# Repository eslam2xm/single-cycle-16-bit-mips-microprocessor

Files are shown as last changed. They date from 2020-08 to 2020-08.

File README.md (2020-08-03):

# Mips-Microprocessor
A 16-bit Harvard Architecture Microprocessor ready to run on Spartan-6 FPGA mounted on a PCB board. Our designed PCB layout was manufactured in China. It consists of three main layers.

## Hardware Layer
1. The first stage of the design is implementing the Microprocessor's all circuital components on a schematic sheet starting from the power supply and voltage regulation components, the FPGA, headers specified for our targeted project, and I/O port headers, VCC and GND headers and JTAG headers, also the FPGA'S essential-combined components such as the oscillator, and the caps, reset button and status LEDs, last thing is an SPI memory to store the data
the schematic consists of 7 blocks for the FPGA each block has number of pins for specific purposes, first 4 blocks represent the 4 banks of FPGA, Power Block, GND block and the JTAG interfacing pins block, each connected through nets to the other components/headers.
2. The second stage is the PCB layout design, the PCB mainly contains of 4 layers, top and bottom layers are signal layers, second layer is GND and basically it helps with noise immunity in the microprocessor other that just connecting the ground nets together, the third layer is the power layer and it is divided into 3 sections, each one supplies a specific voltage required by the components , starting from left, 5v, 3.3v, 1.2v
the USB port entry supplies power to the whole circuit, the voltage regulators on the top layer supplies the other 2 sections of the power layer
all the main components and headers are on the top layer and the bottom layer contains the capacitors and resistors needed by the main components
the voltage regulators and the FPGA require capacitors for filtering the input power as the FPGA is so sensitive to changes in voltages and any small change may damage it, the caps are located right under the FPGA in the bottom layer to achieve minimum track lengths and better functionality
there are 2 status LEDs used in the PCB, the first one is for successively programing the FPGA, and the second LED is for successively resetting the Microprocessor

## HDL Layer

> "Architecture and Design/Architecture.png" contains the full MIPS design

Includes all the main components of the microprocessor written in VHDL and Verilog
> Instruction Memory
> Program Counter
> ALU
> Register File
> RAM
> Control Unit

and all are finally Portmapped in one file.
Each component is implemented separately and reached the expectations in the test benches as indvidual component and also as integrated in the project.

The main file for VHDL is "VHDL\Microprocessor\Microprocessor.vhd"

The main file for Verilog is "Verilog\MP.v"

## Assembly Layer

An Application layer written in assembly for the system which involves interfacing with LCD and Keypad. All the LCD and Keypad drivers are self-implemented by our instruction set.

## Building and Synthesizing

You are required to download and install Xise ISE or any simulating tool that allows you to build VHDL codes to be able to build, synthesize and implement the microprocessor.

> You might encounter an ERROR
> Xise ISE might show errors about some files that aren't in the expected directory. All you have to do is redirect each '.vhd' file to your own
> directory.

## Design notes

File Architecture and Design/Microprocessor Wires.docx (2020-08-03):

Signal’s Name | From | To | Comment
Instruction (8 downto 6) | Instruction memory | Rmux2 | SRFW2 = 0
Instruction (5 downto 3) | Instruction memory | Rmux2 | SRFW2 = 1
Rmux2_to_Rmux1 | Rmux2 | Rmux1 | SRFW1 = 0
Rmux1_to_WREG | Rmux1 | WREG signal in Register file | If SRFW1 = 1 => ‘111’ RW = 1
ALU_Result | ALU | DATA mem and Rmux3 | SRFD3 = 0
D_to_DATA_in_RF | DATA mem | Rmux3 | SRFD3 = 1
Rmux3_to_Rmux4 | Rmux3 | Rmux4 | SRFD2 = 0
Program_Counter_Inc | ADDER1 | Rmux4 , PCmux3 , ADDER2 | SRFD2 = 1 PCmux3 = 0
Rmux4_to_Rmux5 | Rmux4 | Rmux5 | SRFD1 = 0
InPort_to_DATA_in_RF | InPort | Rmux5 | SRFD1 = 1
Rmux5_to_DATA_in_RF | Rmux5 | DATA_in signal in Register file | Check comp names and arch in this file
Instruction (5 downto 0) | Instruction memory | Sign extend
SE_Result | Sign extend | ALUmux1 , ADDER2 | SALU = 1
R2 | R2 register file out2 | ALUmux1 , DATAmem input | SALU = 0
ALU_B | ALUmux1 | ALU_B
R1 | R1 register file out 1 | ALU_A, PCmux1 , Outport | SPC1 = 1 DW = 1 , LOP = 1
Instruction (11 downto 9) | Instruction mem | RREG1 register file in 1
Instruction (8 downto 6) | Instruction mem | RREG2 register file in 2
Instruction (2 downto 0) | Instruction mem | ALUmux2 | SALU1 = 0 , SALU0 = 0
PCmux2_to_PCmux1 | PCmux2 | PCmux1 | SPC1 = 0
Program_Counter_Input | PCmux1 | PC
PCmux3_to_PCmux2 | PCmux3 | PCmux2 | SPC2 = 1
ADDER2_to_PCmux3 | ADDER2 | PCmux3 | SPC3 = 1
Program_Counter_Output | PC | ADDER1 , instruction mem | Increment pc
Instruction (15 downto 12) | Instruction mem | CU | OPCODE
ZF | ALU | Two AND gates | Branch
AND1_to_OR | First AND gate | OR gate | ZF.BRCE
AND2_to_OR | Second AND gate | OR gata | BRCNE.NOT(ZF)
SIG_SPC3 | Branch circuit output | PCmux3
Instruction (11 downto 0) | Instruction mem | PCmux2
ALU_FUNC | ALU_MUX2 | ALU FUNC

Instruction => دي السيجنال اللى طالعه من الانستراكشن ميمورى عالحجات الكتير اوى التانية دى

Program_Counter_Output(15 downto 12) & Instruction (11 downto 0) => دى السجنال اللى داخلة علي الماكس المسؤول عن الجامب اللى هو PCmux2

كل دول طبعا غير السجنالز اللى طالعة من الكنترول يونيت واللى اساميهم هى هى الاسامى اللى اسامة حاططها

الصورة اللى جاية دى هي الشكل النهائى بتاع البروسيسور وعليه اسامى الكومبوننت كلها بحيث تبقي فاهم ايه اللى انا كاتبه فوق ده

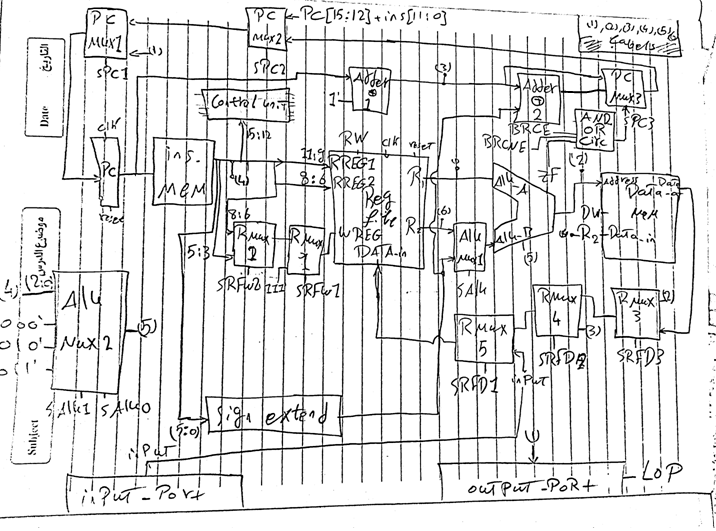
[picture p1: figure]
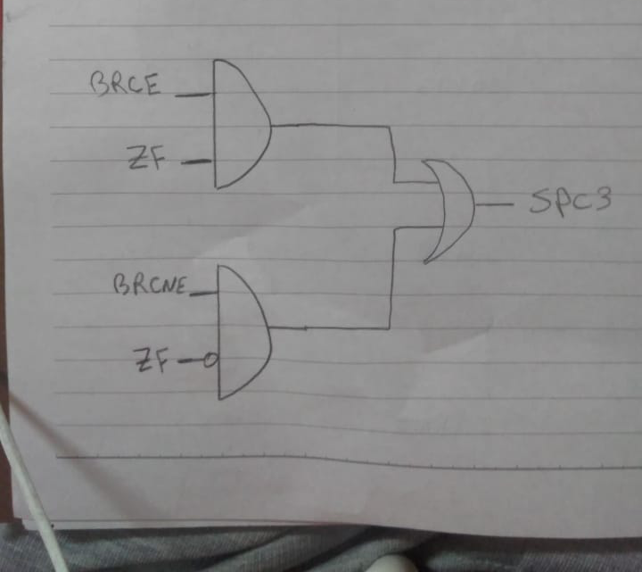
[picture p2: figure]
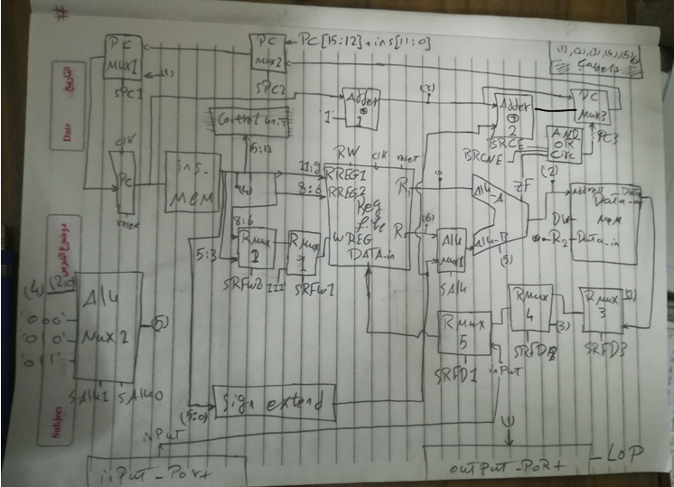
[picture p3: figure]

Instruction
,Rmux2_to_Rmux1
,Rmux1_to_WREG
,ALU_Result
,D_to_DATA_in_RF
,Rmux3_to_Rmux4
,Program_Counter_Inc
,Rmux4_to_Rmux5
,InPort_to_DATA_in_RF
,Rmux5_to_DATA_in_RF
,SE_Result
,R2
,ALU_B
,R1
,PCmux2_to_PCmux1
,Program_Counter_Input
,PCmux3_to_PCmux2
,ADDER2_to_PCmux3
,Program_Counter_Output
,ZF
,AND1_to_OR
,AND2_to_OR
,SIG_SPC3;

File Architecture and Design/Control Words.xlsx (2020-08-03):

instruction | WRF | WRAM | BRCE | BRCNE | SPC2 | SPC1 | SRFD1 | SRFD2 | SRFD3 | SRFW1 | SRFW2 | SALU | LOP | RPC | RRF | SALU1 | SALU0 | LPC
ALU8 | 1 | 0 | 0 | 0 | 1 | 0 | 0 | 0 | 0 | 0 | 1 | 0 | 0 | 0 | 0 | 0 | 0 | 0
IN | 1 | 0 | 0 | 0 | 1 | 0 | 1 | 0 | 0 | 0 | 1 | 0 | 0 | 0 | 0 | 0 | 0 | 0
OUT | 0 | 0 | 0 | 0 | 1 | 0 | 0 | 0 | 0 | 0 | 0 | 0 | 1 | 0 | 0 | 0 | 0 | 0
JR | 0 | 0 | 0 | 0 | 0 | 1 | 0 | 0 | 0 | 0 | 0 | 0 | 0 | 0 | 0 | 0 | 0 | 0
ADDI | 1 | 0 | 0 | 0 | 1 | 0 | 0 | 0 | 0 | 0 | 0 | 1 | 0 | 0 | 0 | 0 | 1 | 0
ANDI | 1 | 0 | 0 | 0 | 1 | 0 | 0 | 0 | 0 | 0 | 0 | 1 | 0 | 0 | 0 | 1 | 0 | 0
ORI | 1 | 0 | 0 | 0 | 1 | 0 | 0 | 0 | 0 | 0 | 0 | 1 | 0 | 0 | 0 | 1 | 1 | 0
LW | 1 | 0 | 0 | 0 | 1 | 0 | 0 | 0 | 1 | 0 | 0 | 1 | 0 | 0 | 0 | 0 | 1 | 0
SW | 0 | 1 | 0 | 0 | 1 | 0 | 0 | 0 | 0 | 0 | 0 | 1 | 0 | 0 | 0 | 0 | 1 | 0
BEQ | 0 | 0 | 1 | 0 | 1 | 0 | 0 | 0 | 0 | 0 | 0 | 0 | 0 | 0 | 0 | 0 | 0 | 0
BNE | 0 | 0 | 0 | 1 | 1 | 0 | 0 | 0 | 0 | 0 | 0 | 0 | 0 | 0 | 0 | 0 | 0 | 0
J | 0 | 0 | 0 | 0 | 0 | 0 | 0 | 0 | 0 | 0 | 0 | 0 | 0 | 0 | 0 | 0 | 0 | 0
JAL | 1 | 0 | 0 | 0 | 0 | 0 | 0 | 1 | 0 | 1 | 0 | 0 | 0 | 0 | 0 | 0 | 0 | 0
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

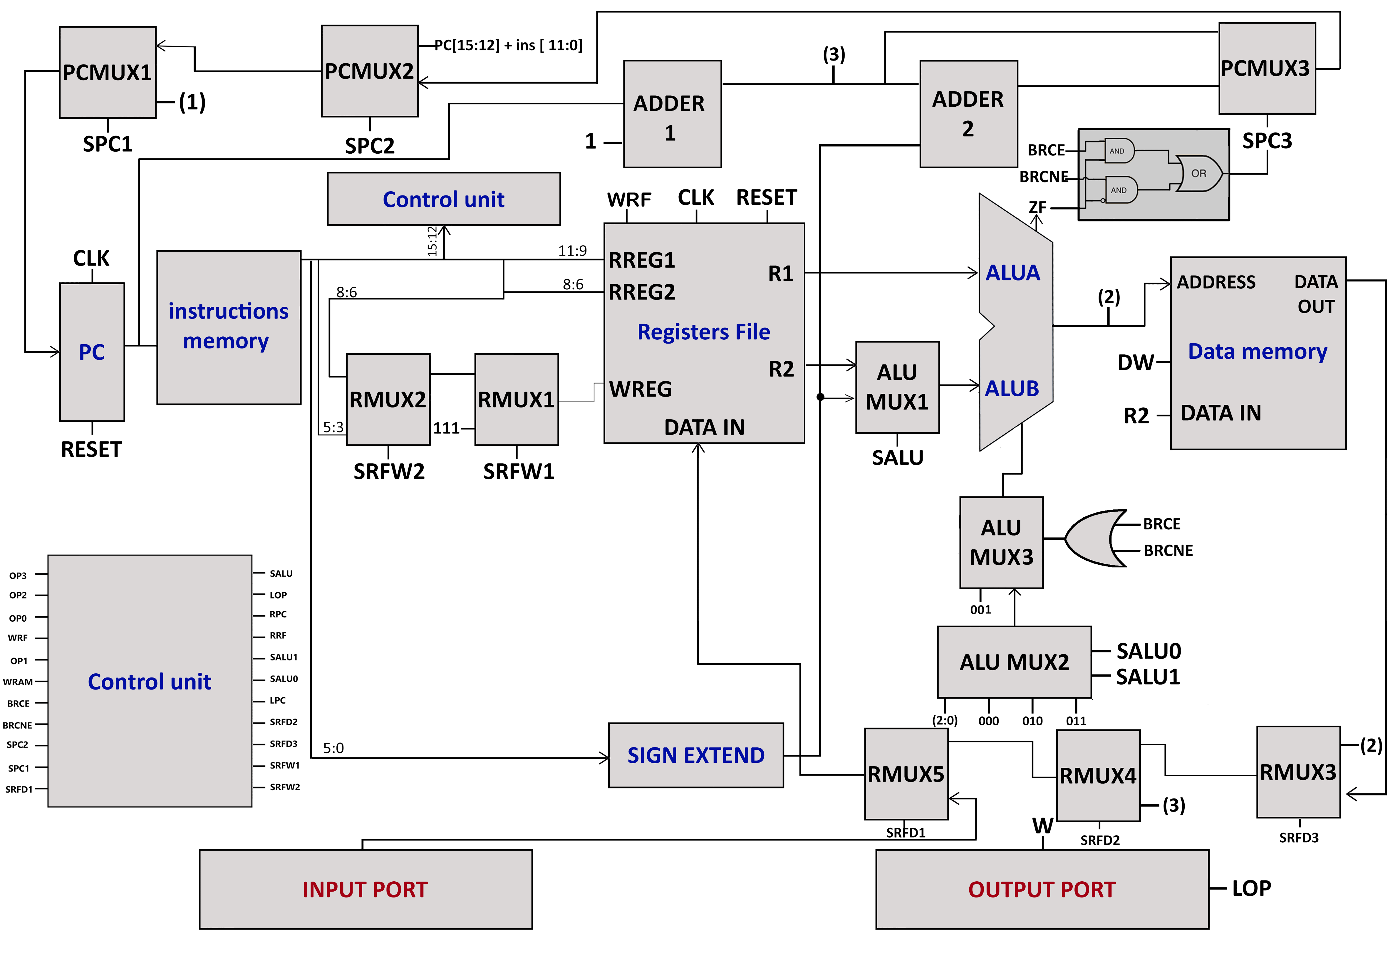
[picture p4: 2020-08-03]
Architecture and Design/Architecture .png

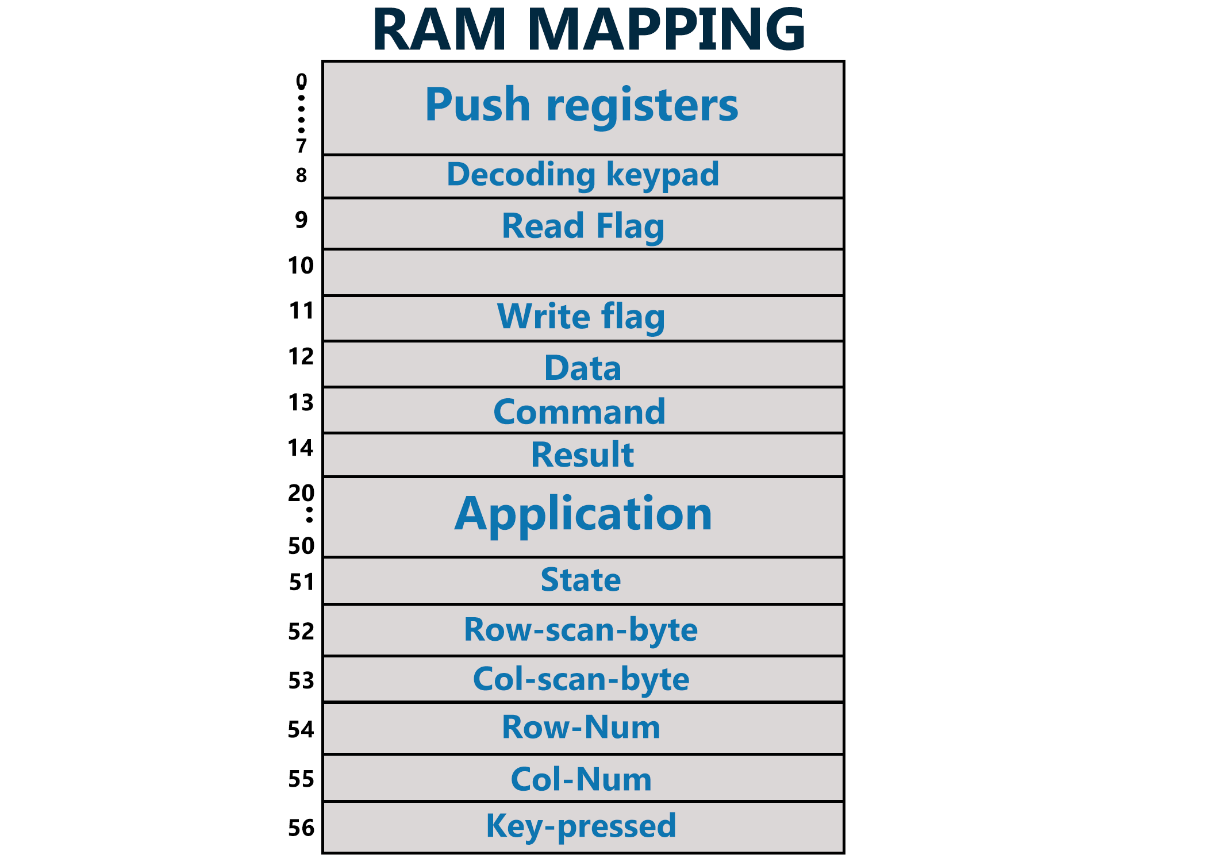
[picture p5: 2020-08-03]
Architecture and Design/RAMMAPPING.png

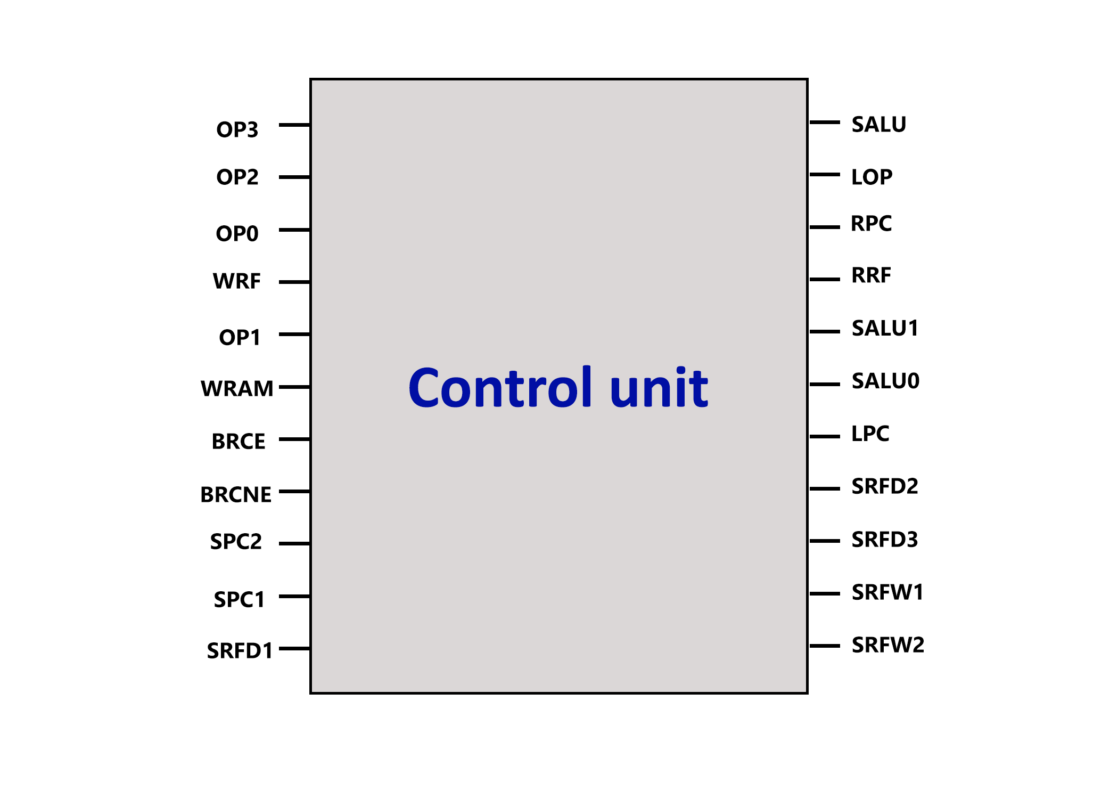
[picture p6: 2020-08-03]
Architecture and Design/Control Unit.png

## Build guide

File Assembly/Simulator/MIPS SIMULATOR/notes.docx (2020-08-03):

NOTES :

Before using the program please test each instruction beforehand so you d be sure every thing works as you intend it to be

User interface :

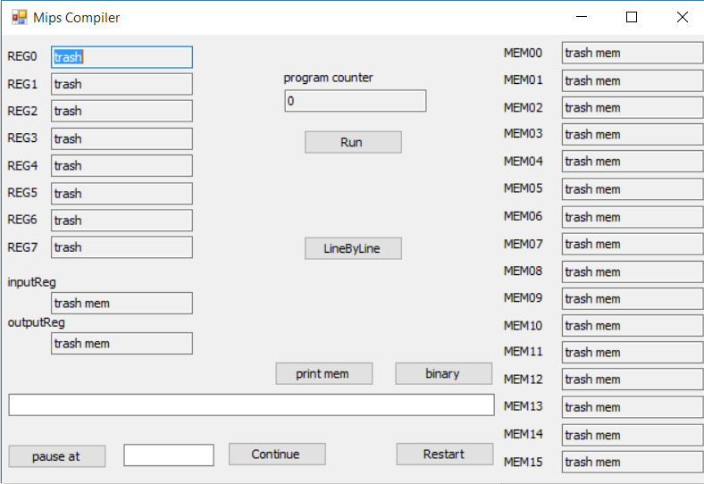
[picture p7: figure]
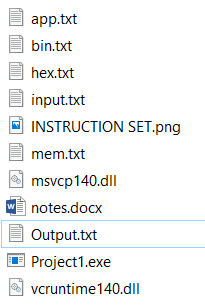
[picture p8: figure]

The program reads your application from app.txt

Press restart then run to run the entire program or line by line to ....

Binary prints your code in binary and hex , print memory prints your mem in hex values inside the file mem.txt

Pause at can pause the program when it reaches a certain line

(pause takes more time in execution so be paitent )

Continue continues the program from where u paused

All user interface values are hexdecimal

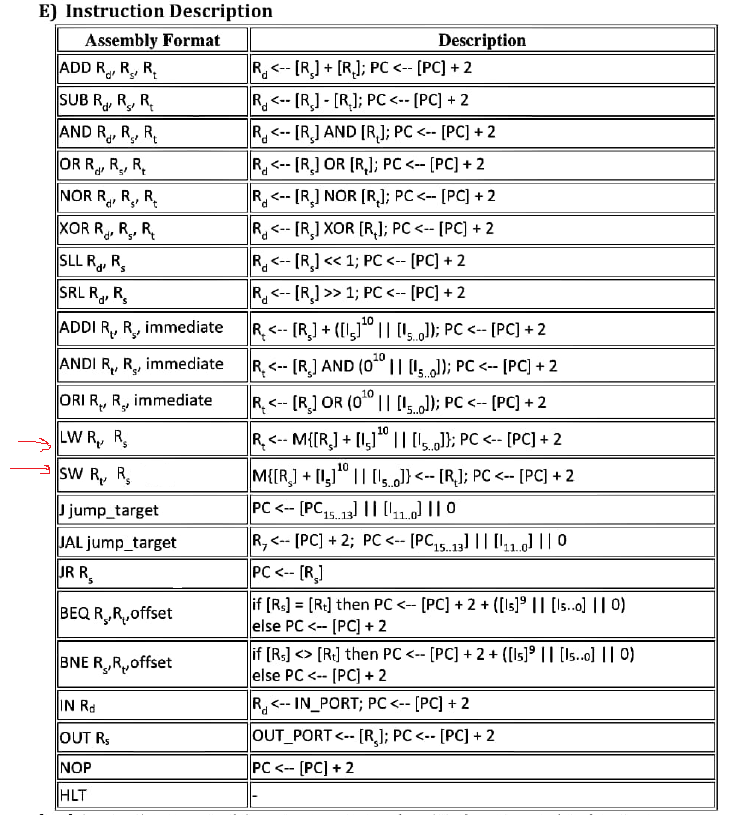
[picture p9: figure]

Please note we eraesed the offset in LW and SW

how to write instructions

*All lines have to be capital and all numbers have to be decimel

Example: ORI R6, R6, 15

*Maximum value for immidiate numbers inside the instruction is 31 ; its supposed to be 63 but it caused some problems so test it yourself before going over 31

*imidiate value for 2 is 02 not 2 and zero is 00 and so on , and ofcorse imidiate calue is decimal

*DO NOT LEAVE UNNECASRY SPACES preferably no spaces at all

Jump :

All labels has to start with a small x not X and end with “:”

Example :

J xnameOfYourLabel < no “:” when using the label

xnameOfYourLabel: ORI R6, R6, 15 → do not leave the label without instruction

لو حد عندة jump ف سطر اكبر من 2 اس 12 (حجم الجمب ف الانستراكشنز) الاسيمبلر هيترجمها لرقم غلط ف خلوا بالكم تعدلوها ب ايدكم لو عندك label ف سطر اعلى من 4096

OUT :

Puts a certain regester on the output pins so we saved every out inside the out.txt and all the numbers are in hexa

IN :

Takes input from the input pins so you will have to specify the value each time you need it inside the input.txt file

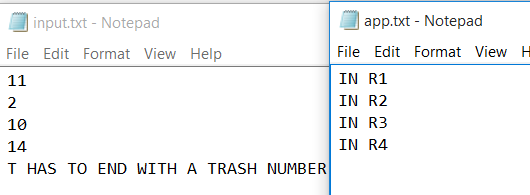
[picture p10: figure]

ALL Input are decimal values

*Memory:

As for memory file it contains only the memories that has a non zero value

Mem has 2^16 adress that is xFFFF as specified in the instruction sheet

If the program crashes that means you made an infinite loop

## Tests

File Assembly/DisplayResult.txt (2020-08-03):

// This segment get the result from Ram14 then seperates it into 5 digits and prints them to the bottom right of the LCD
//Instead of dividing by 10, we calculate the remainder first by multiplying by approx 0.9 using a series of SLL(multiplying by 2) and SRL(dividing by 2)
//----THIS SEGMENT WILL CHANGE R0~4 VALUES AND WILL NOT RETURN THEM TO THEIR INITIAL VALUES-----
//----INSTEAD R0-R4 WILL RETURN WITH ZERO VALUES----
//Used Ram14-result , Ram12-data , Ram13-command , Ram0~7- Push and Pop registers
//Used R0,R1,R2,R3,R4 in calculations and R6 to access the RAM
//Total delays of 10 LCD calls (40 ms), no local delays used

xDISPLAYRESULT: NOP
//Push R7 only, Needs to be pushed so its value can be retained to return to main after execution
SUB R6,R6,R6
ADDI R6,R6,07
SW R7,R6

//Clearing R0~6 except R5
SUB R0,R0,R0
SUB R1,R1,R1
SUB R2,R2,R2
SUB R3,R3,R3
SUB R4,R4,R4
SUB R6,R6,R6

//Get result from Ram14 in R0
ADDI R6,R6,14
LW R0,R6
//save result in R4 too
ADD R4,R4,R0
//R0 = n , R1 = q
//R0 = n>>1
SRL R0,R0
//R1 = n>>1
ADD R1,R1,R0
//R0 = n>>2
SRL R0,R0
//R1 = n>>1 + n>>2 = q
ADD R1,R1,R0
//R2 = q
SUB R2,R2,R2
ADD R2,R1,R2
//R1 = q>>4
SRL R1,R1
SRL R1,R1
SRL R1,R1
SRL R1,R1
//R2 = q + q>>4 = q
ADD R2,R2,R1
//R1 = q
SUB R1,R1,R1
ADD R1,R2,R1
//R1 = q>>8
SRL R1,R1
SRL R1,R1
SRL R1,R1
SRL R1,R1
SRL R1,R1
SRL R1,R1
SRL R1,R1
SRL R1,R1
//R2 = q + q>>8 = q
ADD R2,R2,R1
//R2 = q >> 3 = q
SRL R2,R2 
SRL R2,R2
SRL R2,R2
//R1 = q
SUB R1,R1,R1
ADD R1,R2,R1
//R2 = q<<2
SLL R2,R2
SLL R2,R2
//R2 = q<<2 + q
ADD R2,R1,R2
// R2 = (q<<2 + q) << 1
SLL R2,R2
//R0 = result
SUB R0,R0,R0
ADD R0,R0,R4
//R2 = result - ((q<<2) + q) << 1) = r
SUB R2,R0,R2
//R3 = r
SUB R3,R3,R3
ADD R3,R2,R3
//R3 = r+6
ADDI R3,R3,06
//R3 = (r+6)>>4
SRL R3,R3
SRL R3,R3
SRL R3,R3
SRL R3,R3
//R1 = q + ((r+6)>>4) = q DIVISION RESULT
ADD R1,R1,R3
//R0 = result - 10*q      DIVISION REMAINDER
SUB R0,R0,R1
SUB R0,R0,R1
SUB R0,R0,R1
SUB R0,R0,R1
SUB R0,R0,R1
SUB R0,R0,R1
SUB R0,R0,R1
SUB R0,R0,R1
SUB R0,R0,R1
SUB R0,R0,R1
//
//Now the divion result is in R1 and the remainder is in R0
//we will print the remainder in row 2 col 16 and repeat the whole code 4 more times
// row 2 col 16 is command 207 :(
//
//R2 = 207
SUB R2,R2,R2
ADDI R2,R2,31
ADDI R2,R2,31
ADDI R2,R2,31
ADDI R2,R2,31
ADDI R2,R2,31
ADDI R2,R2,31
ADDI R2,R2,21
// Store in Ram13-command
SUB R6,R6,R6
ADDI R6,R6,13
SW R2,R6
//-----------------------------------------------CALL LCD COMMAND ---------------------------------------------
JAL xSENDCMD
//Change R0 to ascii by adding 0x30 = 48
ADDI R0,R0,30
ADDI R0,R0,18
// Store in Ram12-data
SUB R6,R6,R6
ADDI R6,R6,12
SW R0,R6
//------------------------------------------------CALL LCD DATA---------------------------------------------
JAL xSENDDATA
//////////////////////////////////////////////////////////////////////////////////////////
//////////////////////////////////////////////////////////////////////////////////////////
//                          FIRST DIVISION IS DONE				 	//
//			    1 number is displayed					//
//////////////////////////////////////////////////////////////////////////////////////////
//////////////////////////////////////////////////////////////////////////////////////////
// Put the result of division in R0 and R4, from R1 and repeat the whole division 3 times but print in 206~203
SUB R4,R4,R4
ADD R4,R1,R4
SUB R0,R0,R0
ADD R0,R1,R0
SUB R1,R1,R1
SUB R2,R2,R2
SUB R3,R3,R3
//
//
//Now repeating the division -- 2nd time
//
//
//R0 = n , R1 = q
//R0 = n>>1
SRL R0,R0
//R1 = n>>1
ADD R1,R1,R0
//R0 = n>>2
SRL R0,R0
//R1 = n>>1 + n>>2 = q
ADD R1,R1,R0
//R2 = q
SUB R2,R2,R2
ADD R2,R1,R2
//R1 = q>>4
SRL R1,R1
SRL R1,R1
SRL R1,R1
SRL R1,R1
//R2 = q + q>>4 = q
ADD R2,R2,R1
//R1 = q
SUB R1,R1,R1
ADD R1,R2,R1
//R1 = q>>8
SRL R1,R1
SRL R1,R1
SRL R1,R1
SRL R1,R1
SRL R1,R1
SRL R1,R1
SRL R1,R1
SRL R1,R1
//R2 = q + q>>8 = q
ADD R2,R2,R1
//R2 = q >> 3 = q
SRL R2,R2 
SRL R2,R2
SRL R2,R2
//R1 = q
SUB R1,R1,R1
ADD R1,R2,R1
//R2 = q<<2
SLL R2,R2
SLL R2,R2
//R2 = q<<2 + q
ADD R2,R1,R2
// R2 = (q<<2 + q) << 1
SLL R2,R2
//R0 = result
SUB R0,R0,R0
ADD R0,R0,R4
//R2 = result - ((q<<2) + q) << 1) = r
SUB R2,R0,R2
//R3 = r
SUB R3,R3,R3
ADD R3,R2,R3
//R3 = r+6
ADDI R3,R3,06
//R3 = (r+6)>>4
SRL R3,R3
SRL R3,R3
SRL R3,R3
SRL R3,R3
//R1 = q + ((r+6)>>4) = q DIVISION RESULT
ADD R1,R1,R3
//R0 = result - 10*q      DIVISION REMAINDER
SUB R0,R0,R1
SUB R0,R0,R1
SUB R0,R0,R1
SUB R0,R0,R1
SUB R0,R0,R1
SUB R0,R0,R1
SUB R0,R0,R1
SUB R0,R0,R1
SUB R0,R0,R1
SUB R0,R0,R1
//
//Now the divion result is in R1 and the remainder is in R0
//we will print the remainder in row 2 col 15 and repeat the whole code 4 more times
// row 2 col 16 is command 206 
//
//R2 = 206
SUB R2,R2,R2
ADDI R2,R2,31
ADDI R2,R2,31
ADDI R2,R2,31
ADDI R2,R2,31
ADDI R2,R2,31
ADDI R2,R2,31
ADDI R2,R2,20
// Store in Ram13-command
SUB R6,R6,R6
ADDI R6,R6,13
SW R2,R6
//-----------------------------------------------CALL LCD COMMAND ---------------------------------------------
JAL xSENDCMD
//Change R0 to ascii by adding 0x30 = 48
ADDI R0,R0,30
ADDI R0,R0,18
// Store in Ram12-data
SUB R6,R6,R6
ADDI R6,R6,12
SW R0,R6
//------------------------------------------------CALL LCD DATA---------------------------------------------
JAL xSENDDATA
//////////////////////////////////////////////////////////////////////////////////////////
//////////////////////////////////////////////////////////////////////////////////////////
//                          SECOND DIVISION IS DONE				 	//
//			    2 numbers are displayed					//
//////////////////////////////////////////////////////////////////////////////////////////
//////////////////////////////////////////////////////////////////////////////////////////
//  Put the result of division in R0 and R4, from R1 and repeat the whole division 2 more times but print in 205~203
SUB R4,R4,R4
ADD R4,R1,R4
SUB R0,R0,R0
ADD R0,R1,R0
SUB R1,R1,R1
SUB R2,R2,R2
SUB R3,R3,R3
//
//
//Now repeating the division -- 3rd time
//
//
//R0 = n , R1 = q
//R0 = n>>1
SRL R0,R0
//R1 = n>>1
ADD R1,R1,R0
//R0 = n>>2
SRL R0,R0
//R1 = n>>1 + n>>2 = q
ADD R1,R1,R0
//R2 = q
SUB R2,R2,R2
ADD R2,R1,R2
//R1 = q>>4
SRL R1,R1
SRL R1,R1
SRL R1,R1
SRL R1,R1
//R2 = q + q>>4 = q
ADD R2,R2,R1
//R1 = q
SUB R1,R1,R1
ADD R1,R2,R1
//R1 = q>>8
SRL R1,R1
SRL R1,R1
SRL R1,R1
SRL R1,R1
SRL R1,R1
SRL R1,R1
SRL R1,R1
SRL R1,R1
//R2 = q + q>>8 = q
ADD R2,R2,R1
//R2 = q >> 3 = q
SRL R2,R2 
SRL R2,R2
SRL R2,R2
//R1 = q
SUB R1,R1,R1
ADD R1,R2,R1
//R2 = q<<2
SLL R2,R2
SLL R2,R2
//R2 = q<<2 + q
ADD R2,R1,R2
// R2 = (q<<2 + q) << 1
SLL R2,R2
//R0 = result
SUB R0,R0,R0
ADD R0,R0,R4
LW R0,R6
//R2 = result - ((q<<2) + q) << 1) = r
SUB R2,R0,R2
//R3 = r
SUB R3,R3,R3
ADD R3,R2,R3
//R3 = r+6
ADDI R3,R3,06
//R3 = (r+6)>>4
SRL R3,R3
SRL R3,R3
SRL R3,R3
SRL R3,R3
//R1 = q + ((r+6)>>4) = q DIVISION RESULT
ADD R1,R1,R3
//R0 = result - 10*q      DIVISION REMAINDER
SUB R0,R0,R1
SUB R0,R0,R1
SUB R0,R0,R1
SUB R0,R0,R1
SUB R0,R0,R1
SUB R0,R0,R1
SUB R0,R0,R1
SUB R0,R0,R1
SUB R0,R0,R1
SUB R0,R0,R1
//
//Now the divion result is in R1 and the remainder is in R0
//we will print the remainder in row 2 col 14 and repeat the code 2 more times
// row 2 col 16 is command 206 
//
//R2 = 205
SUB R2,R2,R2
ADDI R2,R2,31
ADDI R2,R2,31
ADDI R2,R2,31
ADDI R2,R2,31
ADDI R2,R2,31
ADDI R2,R2,31
ADDI R2,R2,19
// Store in Ram13-command
SUB R6,R6,R6
ADDI R6,R6,13
SW R2,R6
//-----------------------------------------------CALL LCD COMMAND ---------------------------------------------
JAL xSENDCMD
//Change R0 to ascii by adding 0x30 = 48
ADDI R0,R0,30
ADDI R0,R0,18
// Store in Ram12-data
SUB R6,R6,R6
ADDI R6,R6,12
SW R0,R6
//------------------------------------------------CALL LCD DATA---------------------------------------------
JAL xSENDDATA
//  Put the result of division in R0 and R4, from R1 and repeat the whole division 3 more times but print in 205~203
SUB R0,R0,R0
ADD R0,R1,R0
SUB R1,R1,R1
SUB R2,R2,R2
SUB R3,R3,R3
//////////////////////////////////////////////////////////////////////////////////////////
//////////////////////////////////////////////////////////////////////////////////////////
//                          THIRED DIVISION IS DONE				 	//
//			    3 numbers are displayed					//
//////////////////////////////////////////////////////////////////////////////////////////
//////////////////////////////////////////////////////////////////////////////////////////
//  Put the result of division in R0 and R4, from R1 and repeat the whole division 1 more time but print in 204~203
SUB R4,R4,R4
ADD R4,R1,R4
SUB R0,R0,R0
ADD R0,R1,R0
SUB R1,R1,R1
SUB R2,R2,R2
SUB R3,R3,R3
//
//
//Now repeating the division -- 4th time
//
//
//R0 = n , R1 = q
//R0 = n>>1
SRL R0,R0
//R1 = n>>1
ADD R1,R1,R0
//R0 = n>>2
SRL R0,R0
//R1 = n>>1 + n>>2 = q
ADD R1,R1,R0
//R2 = q
SUB R2,R2,R2
ADD R2,R1,R2
//R1 = q>>4
SRL R1,R1
SRL R1,R1
SRL R1,R1
SRL R1,R1
//R2 = q + q>>4 = q
ADD R2,R2,R1
//R1 = q
SUB R1,R1,R1
ADD R1,R2,R1
//R1 = q>>8
SRL R1,R1
SRL R1,R1
SRL R1,R1
SRL R1,R1
SRL R1,R1
SRL R1,R1
SRL R1,R1
SRL R1,R1
//R2 = q + q>>8 = q
ADD R2,R2,R1
//R2 = q >> 3 = q
SRL R2,R2 
SRL R2,R2
SRL R2,R2
//R1 = q
SUB R1,R1,R1
ADD R1,R2,R1
//R2 = q<<2
SLL R2,R2
SLL R2,R2
//R2 = q<<2 + q
ADD R2,R1,R2
// R2 = (q<<2 + q) << 1
SLL R2,R2
//R0 = result
SUB R0,R0,R0
ADD R0,R0,R4
LW R0,R6
//R2 = result - ((q<<2) + q) << 1) = r
SUB R2,R0,R2
//R3 = r
SUB R3,R3,R3
ADD R3,R2,R3
//R3 = r+6
ADDI R3,R3,06
//R3 = (r+6)>>4
SRL R3,R3
SRL R3,R3
SRL R3,R3
SRL R3,R3
//R1 = q + ((r+6)>>4) = q DIVISION RESULT
ADD R1,R1,R3
//R0 = result - 10*q      DIVISION REMAINDER
SUB R0,R0,R1
SUB R0,R0,R1
SUB R0,R0,R1
SUB R0,R0,R1
SUB R0,R0,R1
SUB R0,R0,R1
SUB R0,R0,R1
SUB R0,R0,R1
SUB R0,R0,R1
SUB R0,R0,R1
//
//Now the divion result is in R1 and the remainder is in R0
//we will print the remainder in row 2 col 13
// row 2 col 13 is command 204 
//
//R2 = 204
SUB R2,R2,R2
ADDI R2,R2,31
ADDI R2,R2,31
ADDI R2,R2,31
ADDI R2,R2,31
ADDI R2,R2,31
ADDI R2,R2,31
ADDI R2,R2,18
// Store in Ram13-command
SUB R6,R6,R6
ADDI R6,R6,13
SW R2,R6
//-----------------------------------------------CALL LCD COMMAND ---------------------------------------------
JAL xSENDCMD
//Change R0 to ascii by adding 0x30 = 48
ADDI R0,R0,30
ADDI R0,R0,18
// Store in Ram12-data
SUB R6,R6,R6
ADDI R6,R6,12
SW R0,R6
//------------------------------------------------CALL LCD DATA---------------------------------------------
JAL xSENDDATA
//////////////////////////////////////////////////////////////////////////////////////////
//////////////////////////////////////////////////////////////////////////////////////////
//                          FOURTH DIVISION IS DONE				 	//
//			    4 numbers are displayed					//
//////////////////////////////////////////////////////////////////////////////////////////
//////////////////////////////////////////////////////////////////////////////////////////
//Now the last digit to print is the result of dividing by 10 for 4 times, dividing by 10,000, which is stored in R1
//Print in row 2 col 12 
//R2 = 203
SUB R2,R2,R2
ADDI R2,R2,31
ADDI R2,R2,31
ADDI R2,R2,31
ADDI R2,R2,31
ADDI R2,R2,31
ADDI R2,R2,31
ADDI R2,R2,17
// Store in Ram13-command
SUB R6,R6,R6
ADDI R6,R6,13
SW R2,R6
//-----------------------------------------------CALL LCD COMMAND ---------------------------------------------
JAL xSENDCMD
//Change R1 to ascii
ADDI R1,R1,30
ADDI R1,R1,18
// Store in Ram12-data
SUB R6,R6,R6
ADDI R6,R6,12
SW R1,R6
//------------------------------------------------CALL LCD DATA---------------------------------------------
JAL xSENDDATA
//////////////////////////////////////////////////////////////////////////////////////////
//////////////////////////////////////////////////////////////////////////////////////////
//                          	5 Numbers are displayed				 	//
//////////////////////////////////////////////////////////////////////////////////////////
//////////////////////////////////////////////////////////////////////////////////////////
//Clearing the values of R0~4
SUB R0,R0,R0
SUB R1,R1,R1
SUB R2,R2,R2
SUB R3,R3,R3
SUB R4,R4,R4

//Pop R7 to return to main
SUB R6,R6,R6
ADDI R6,R6,07
LW R7,R6

//return back to main
JR R7

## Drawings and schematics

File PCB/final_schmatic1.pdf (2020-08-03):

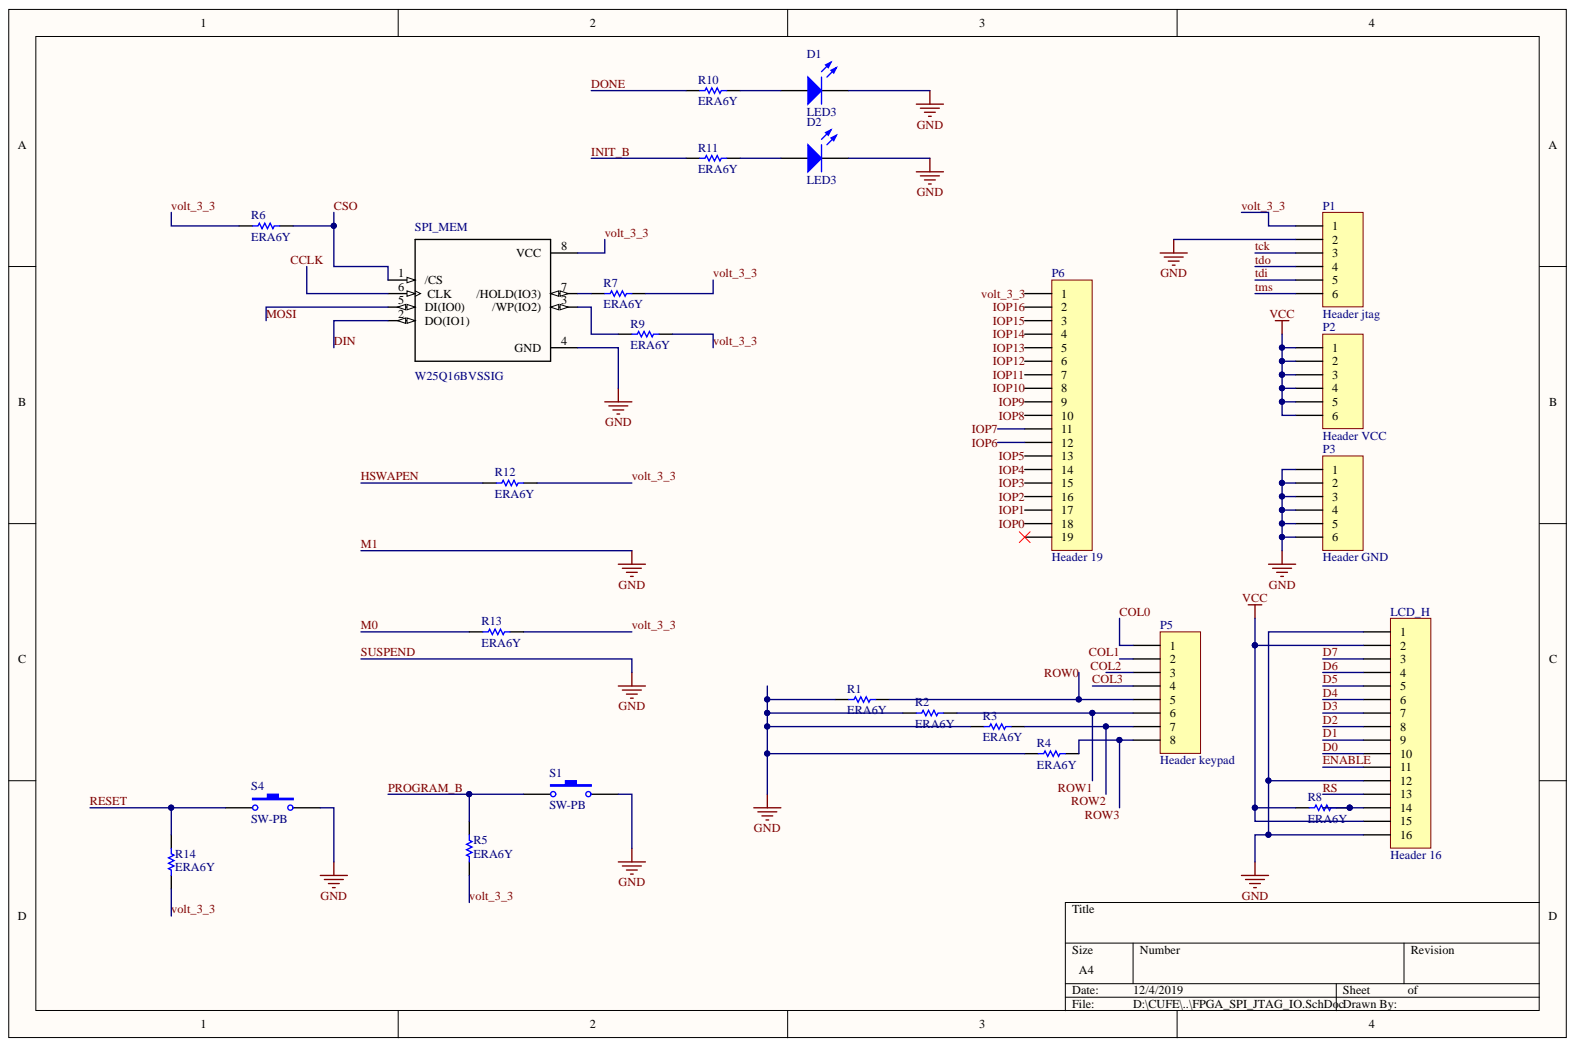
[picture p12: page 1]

Size A4 | Number | Revision

Date: 12/4/2019 | Sheet of
File: D:\CUFE\..\FPGA_SPI_JTAG_IO.SchDocDrawn By:

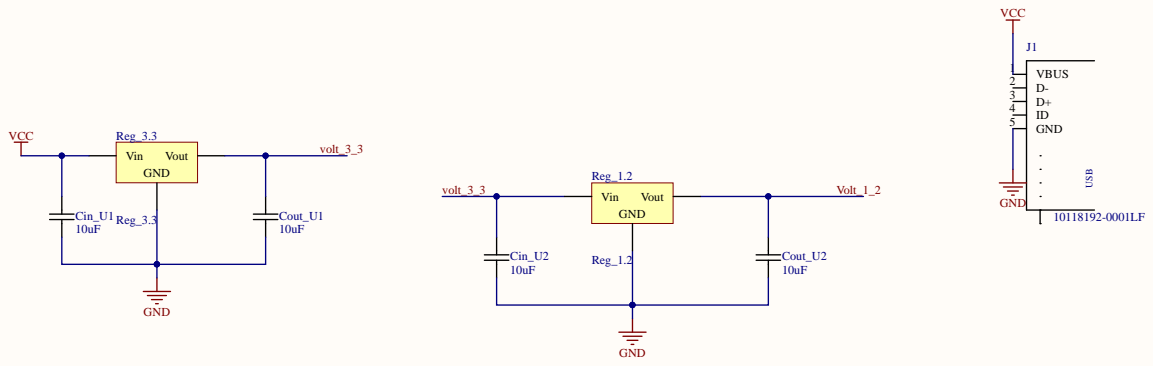
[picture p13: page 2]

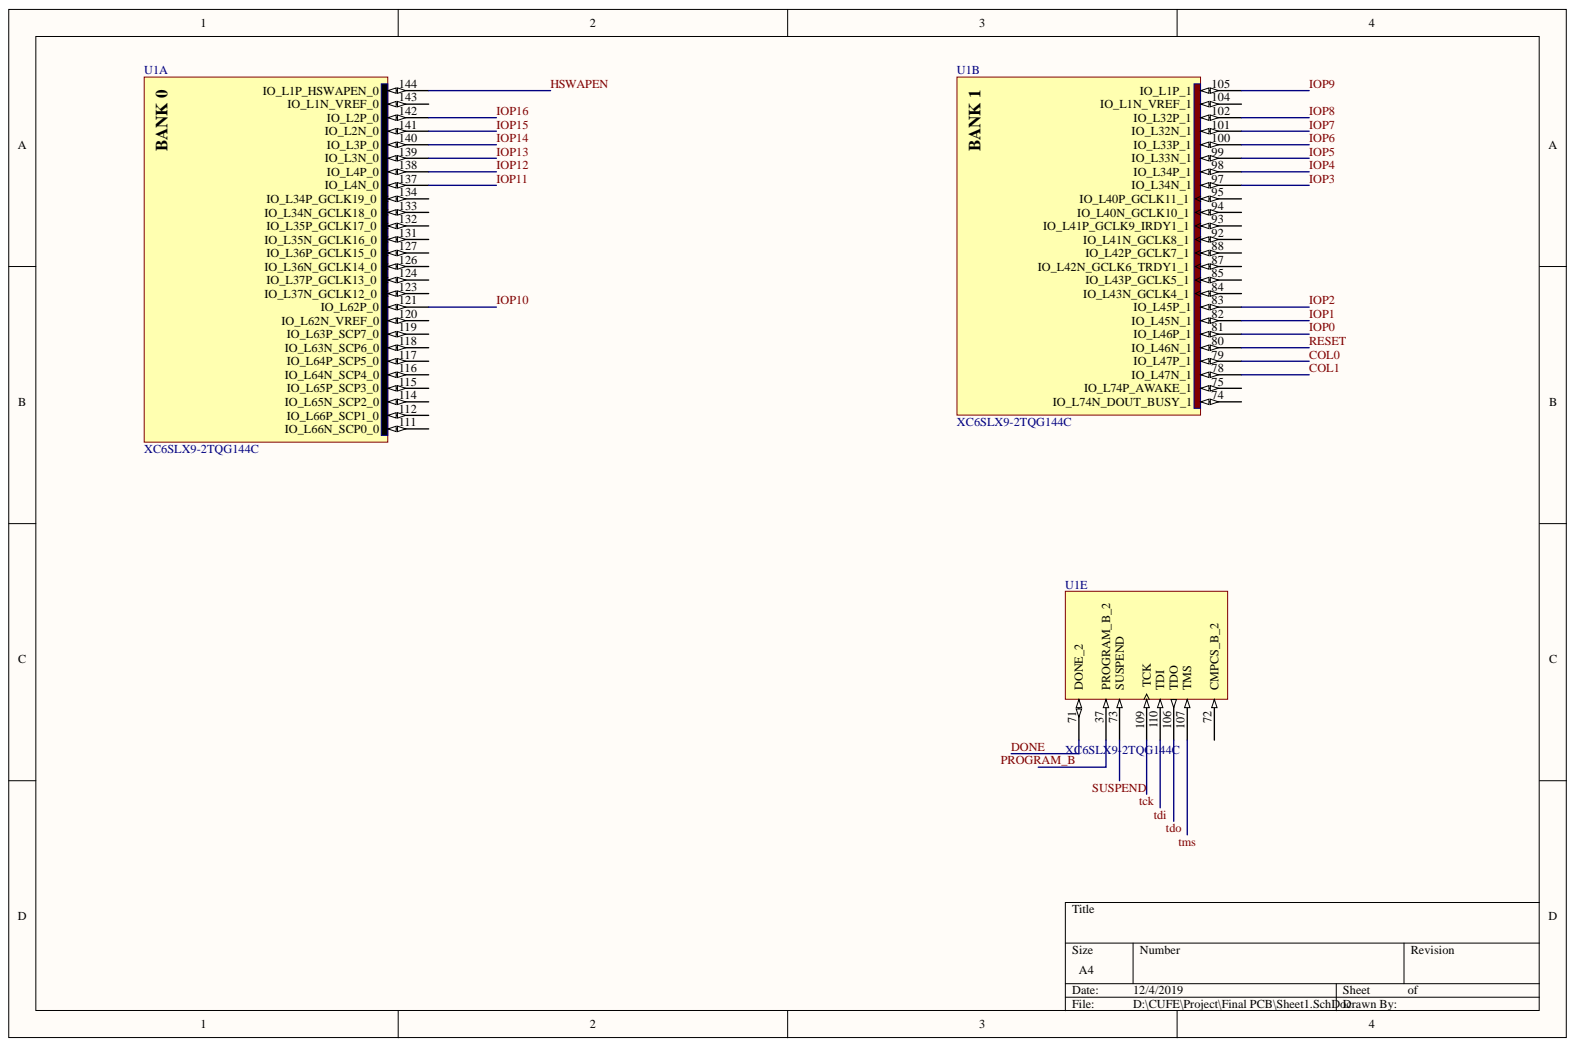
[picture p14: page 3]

Size A4 | Number | Revision

Date: 12/4/2019 | Sheet of
File: D:\CUFE\Project\Final PCB\Sheet1.SchDocDrawn By:

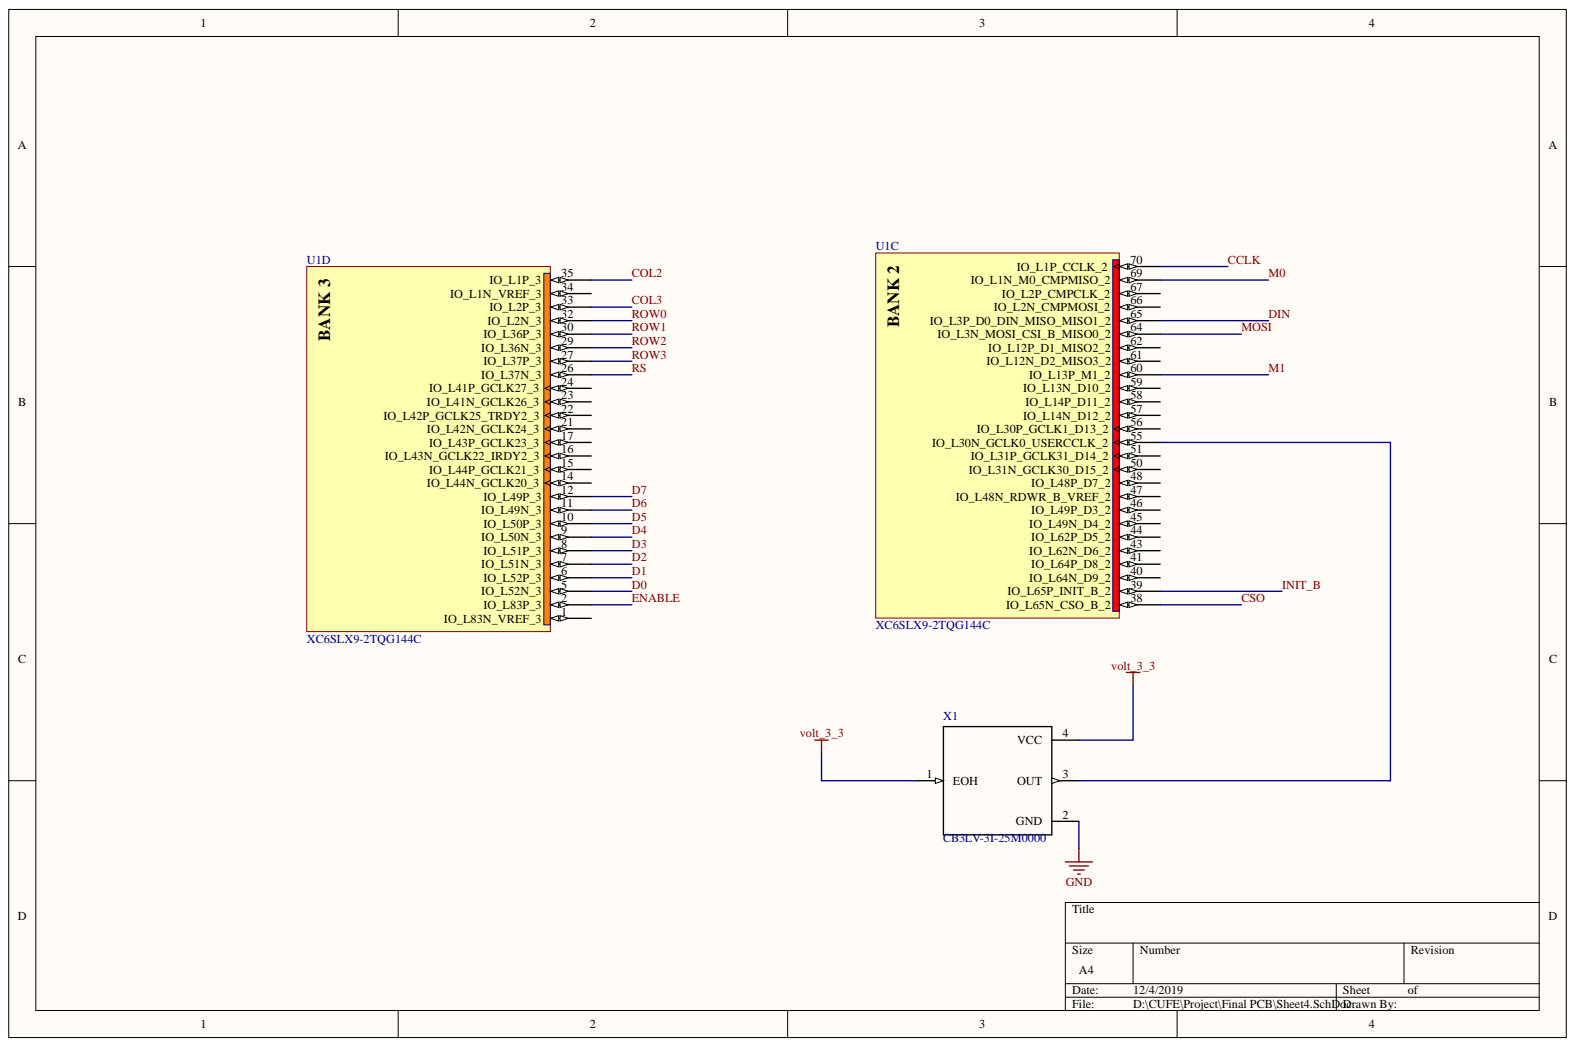
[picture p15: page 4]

Size A4 | Number | Revision

Date: 12/4/2019 | Sheet of
File: D:\CUFE\Project\Final PCB\Sheet4.SchDocDrawn By:

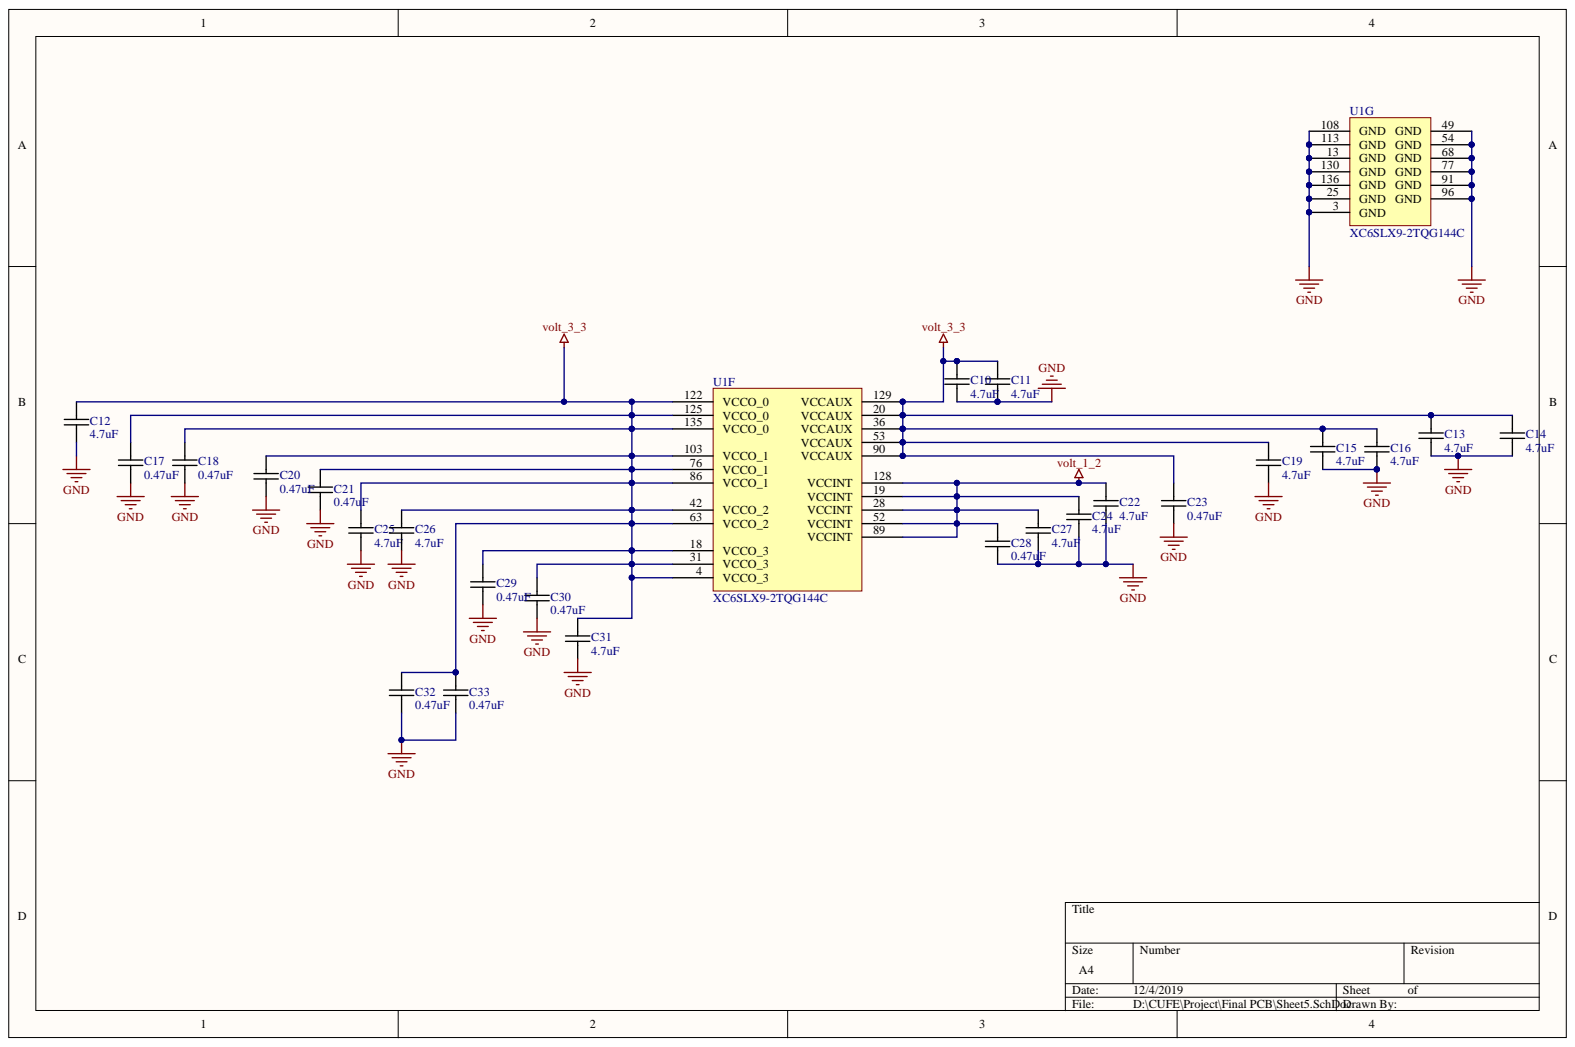
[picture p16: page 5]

VCCO_3 31

Size A4 | Number | Revision

Date: 12/4/2019 | Sheet of
File: D:\CUFE\Project\Final PCB\Sheet5.SchDocDrawn By:

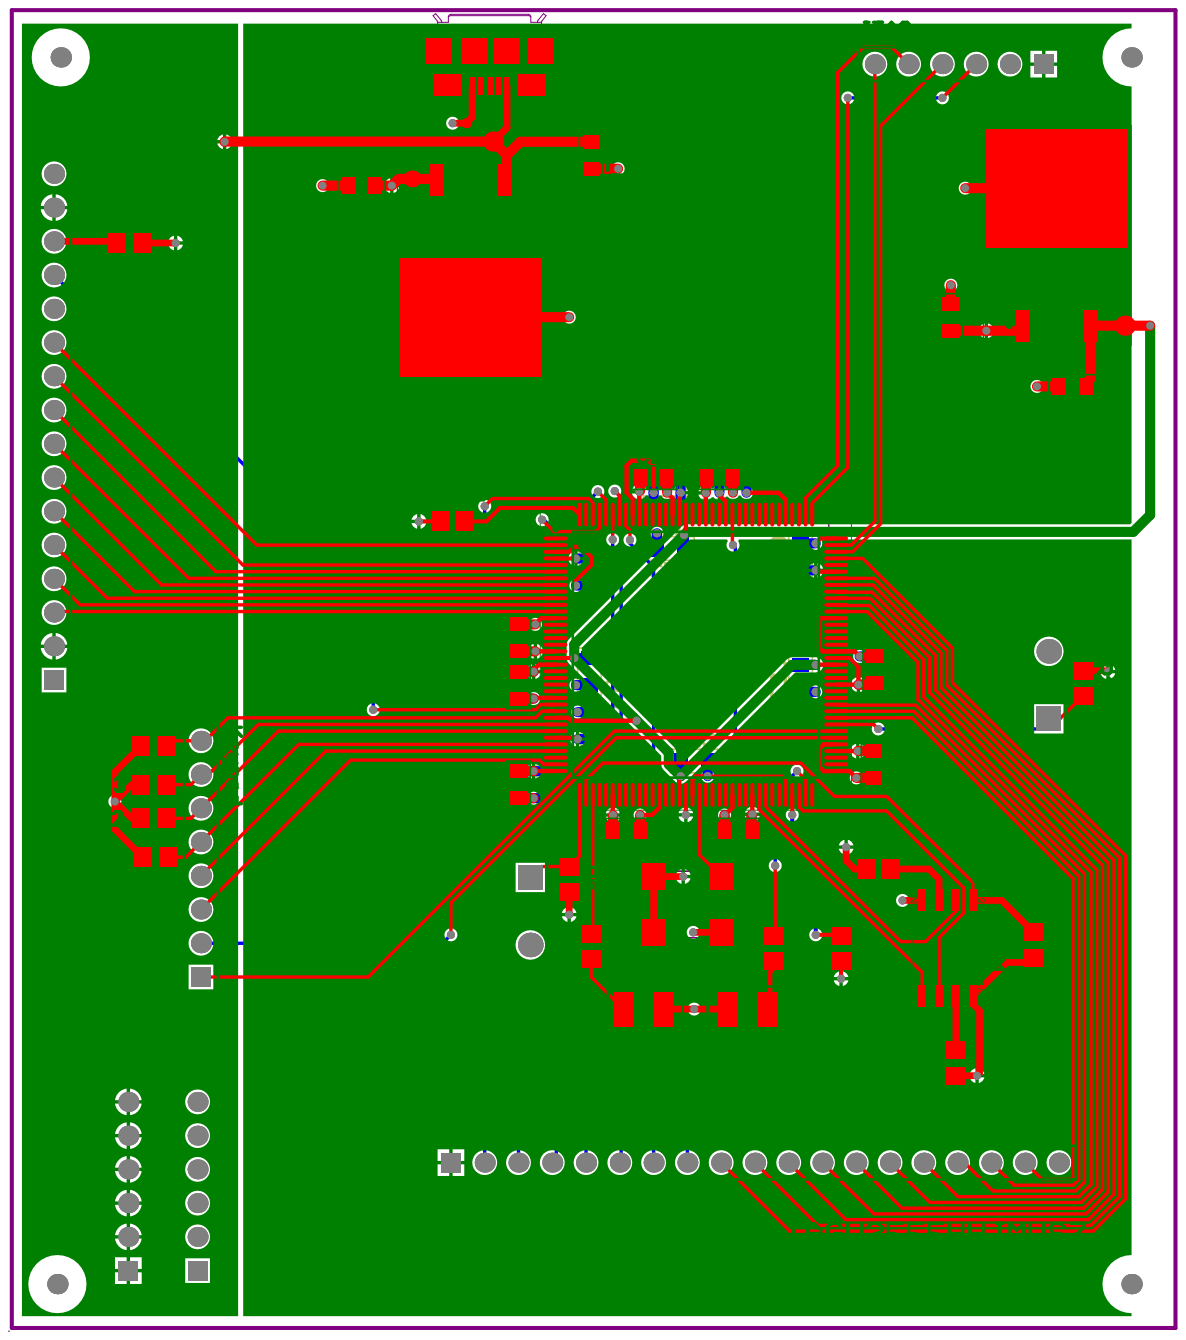
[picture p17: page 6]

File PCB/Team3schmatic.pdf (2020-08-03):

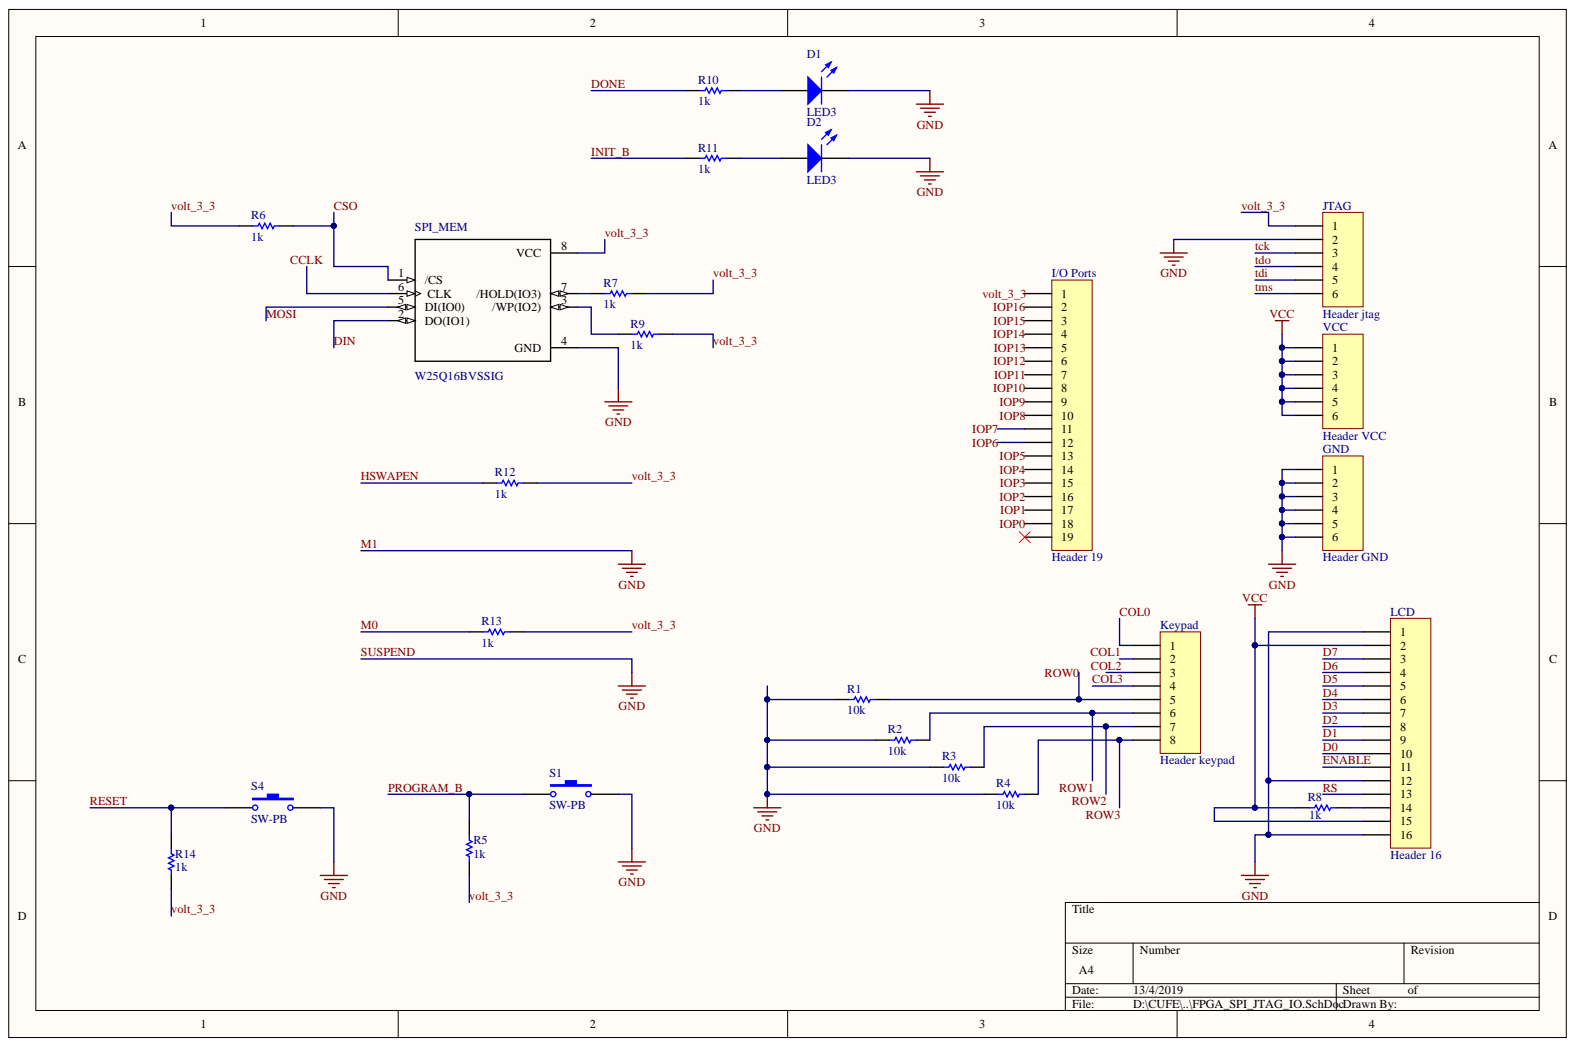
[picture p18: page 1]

Size A4 | Number | Revision

Date: 13/4/2019 | Sheet of
File: D:\CUFE\..\FPGA_SPI_JTAG_IO.SchDocDrawn By:

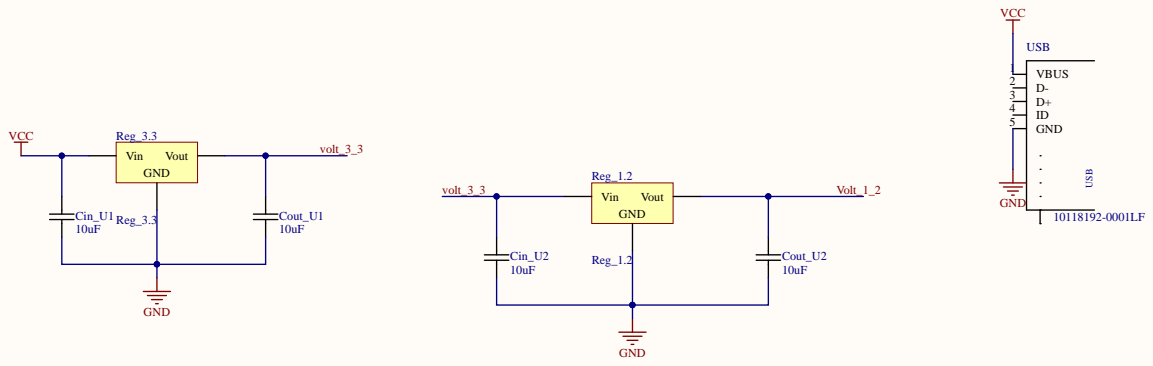
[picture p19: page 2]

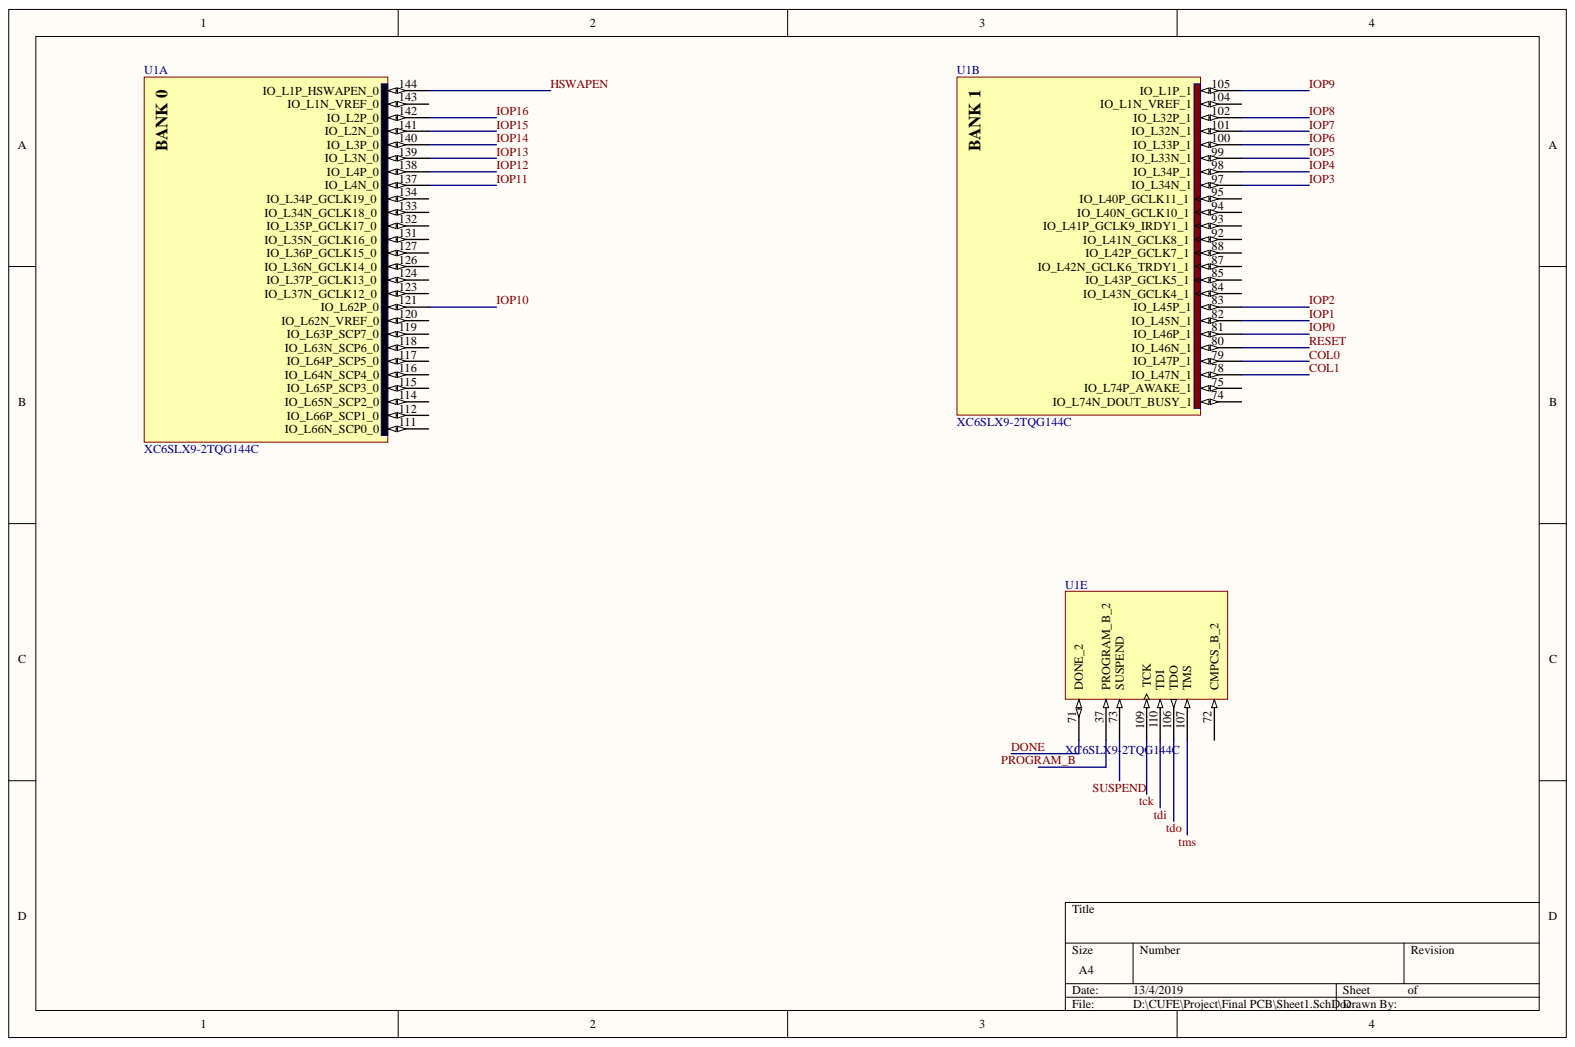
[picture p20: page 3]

Size A4 | Number | Revision

Date: 13/4/2019 | Sheet of
File: D:\CUFE\Project\Final PCB\Sheet1.SchDocDrawn By:

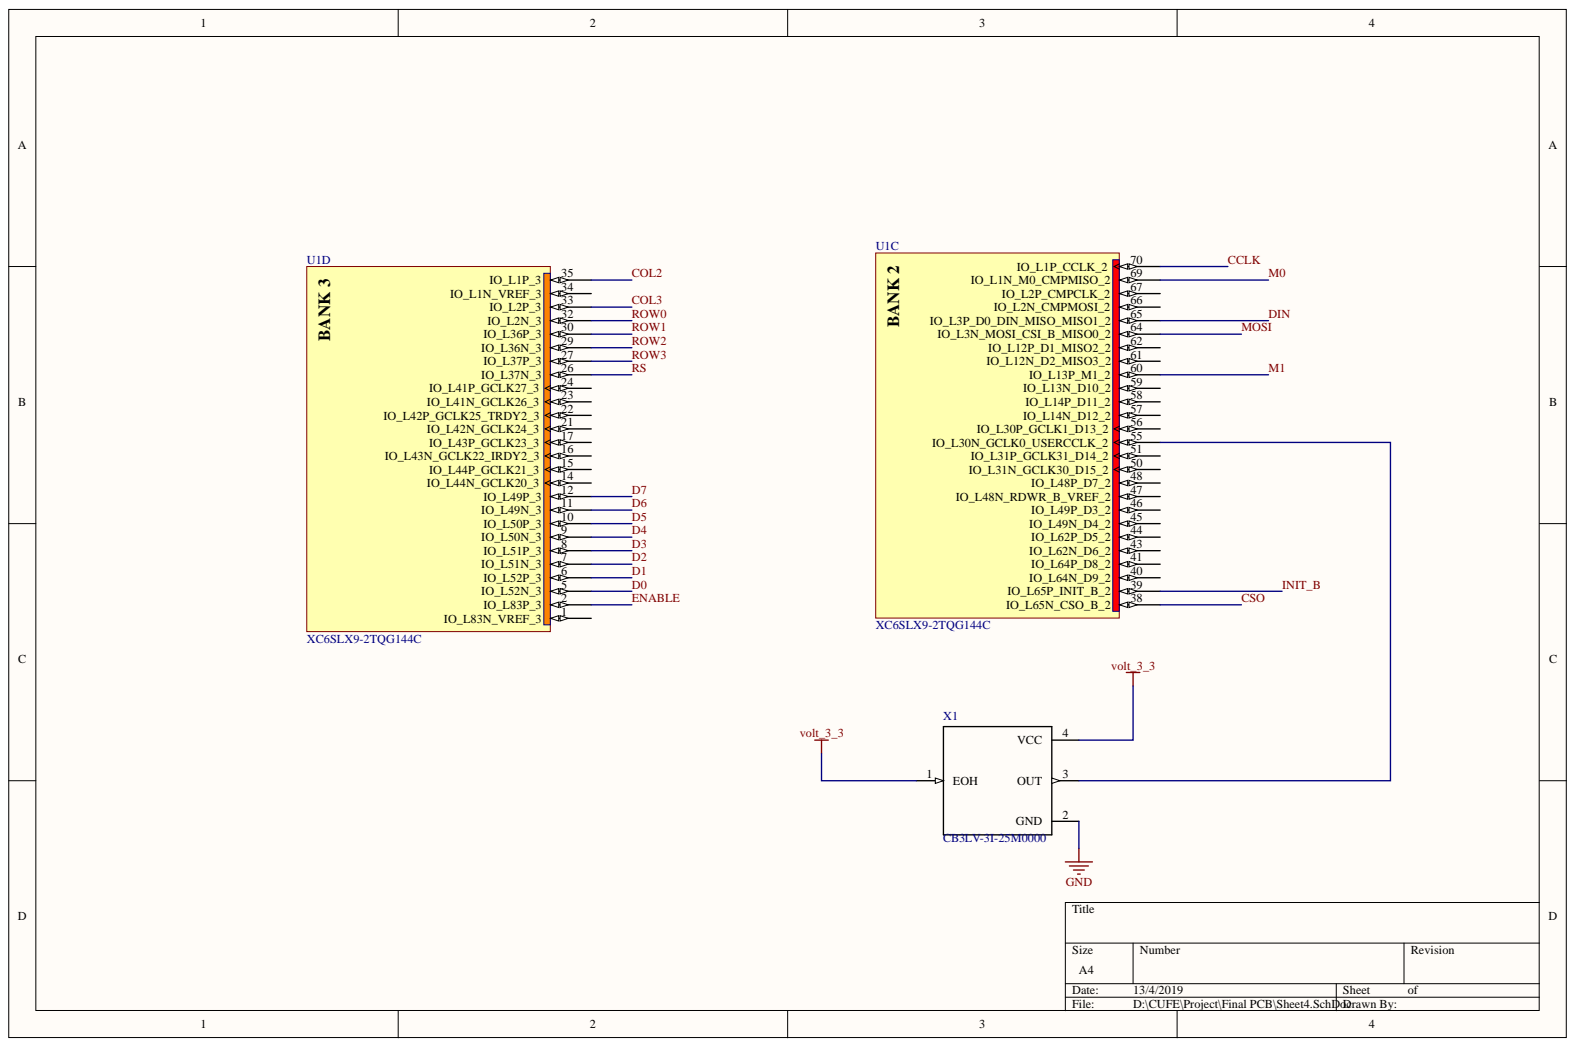
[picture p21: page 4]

Size A4 | Number | Revision

Date: 13/4/2019 | Sheet of
File: D:\CUFE\Project\Final PCB\Sheet4.SchDocDrawn By:

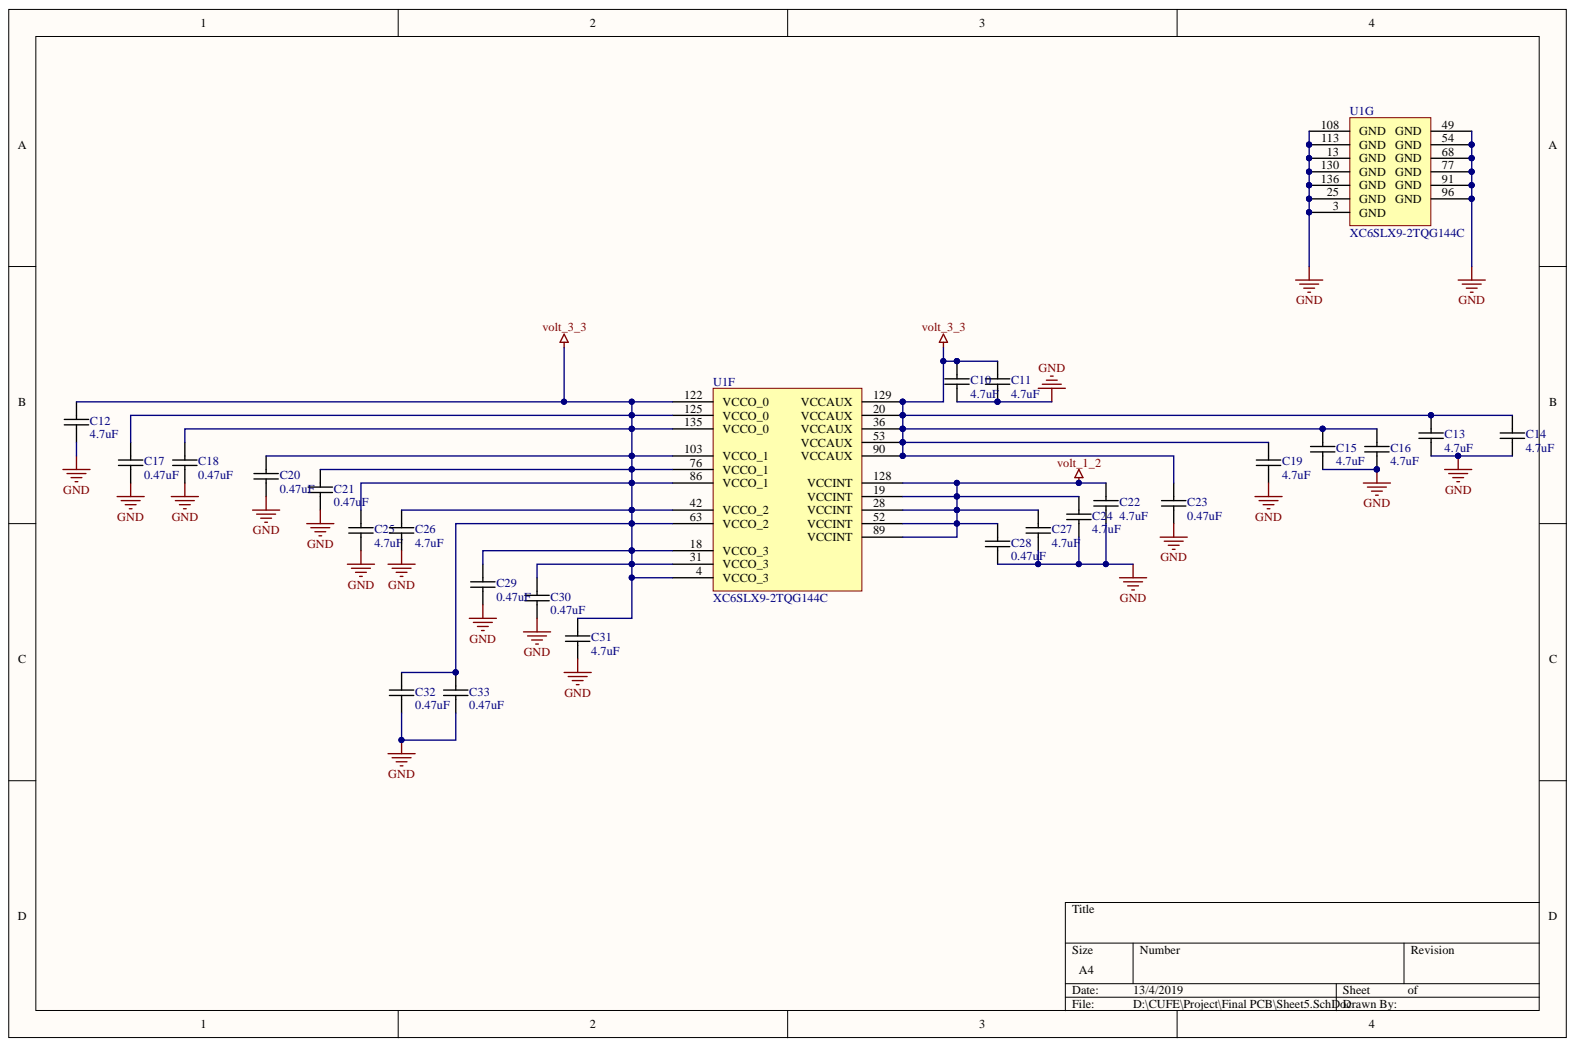
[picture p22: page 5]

VCCO_3 31

Size A4 | Number | Revision

Date: 13/4/2019 | Sheet of
File: D:\CUFE\Project\Final PCB\Sheet5.SchDocDrawn By:

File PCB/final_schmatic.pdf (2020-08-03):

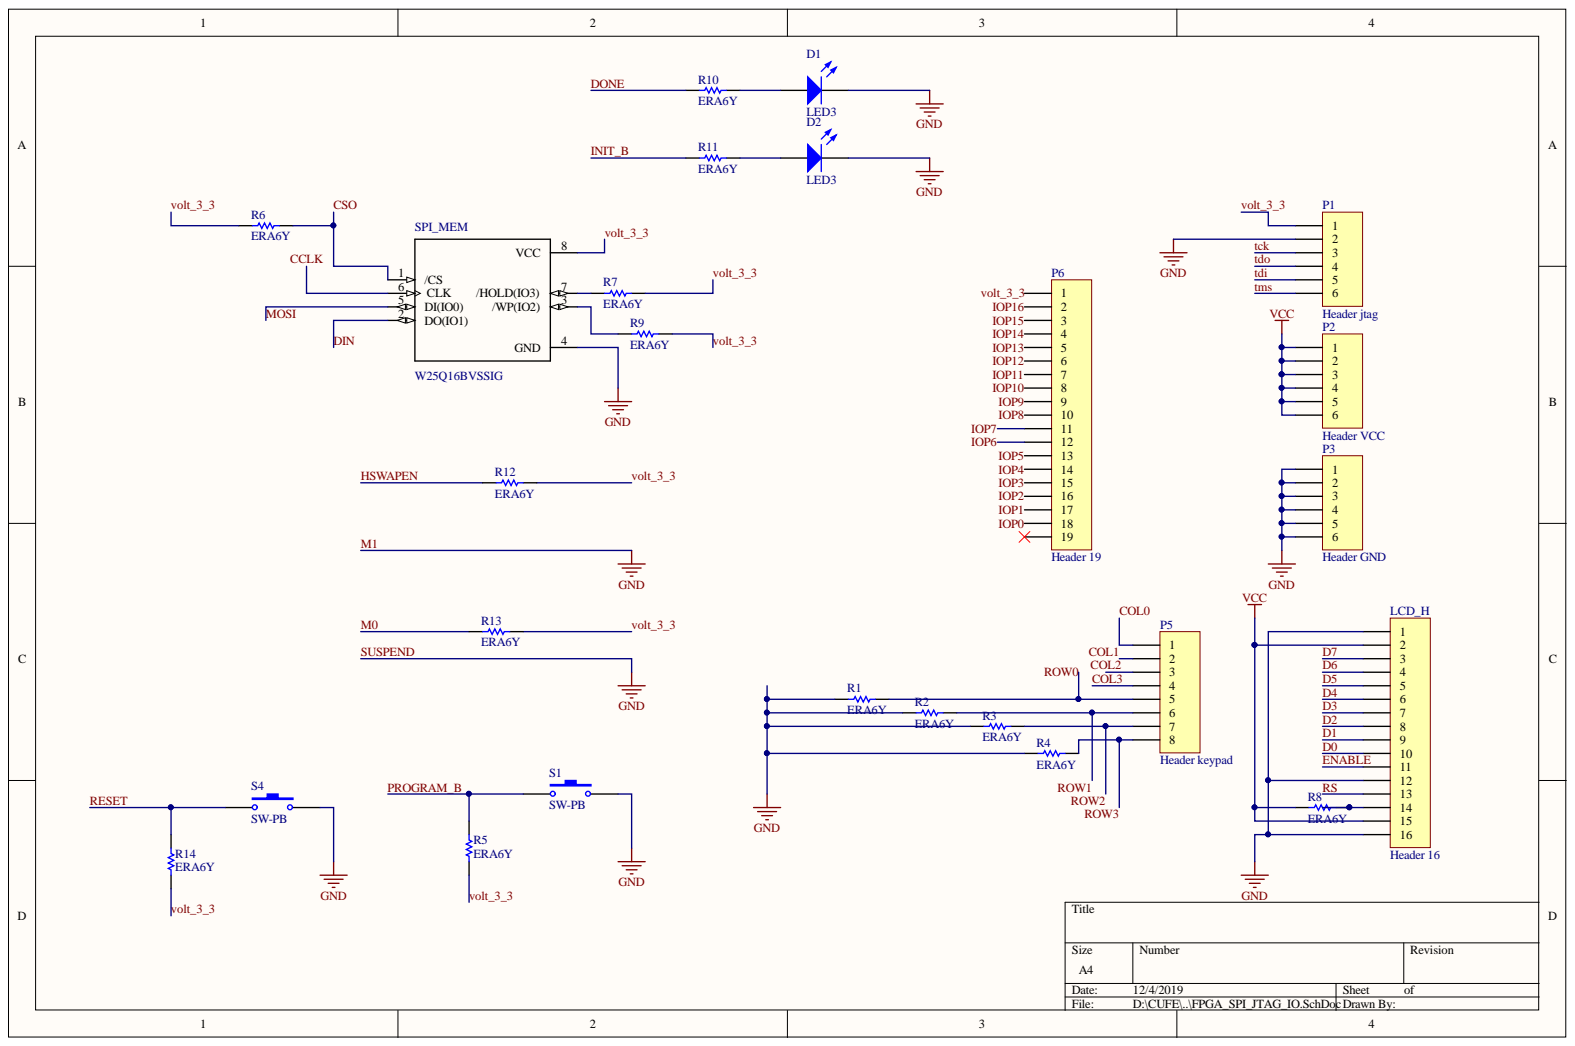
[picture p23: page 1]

Size A4 | Number | Revision

Date: 12/4/2019 | Sheet of
File: D:\CUFE\..\FPGA_SPI_JTAG_IO.SchDocDrawn By:



Numbe r | R evision

: 12/4/2019 | She et of
File : D:\C UFE\P roje ct\Final P C B\She et1. S chDocD | r a wn By:


Numbe r | R evision

: 12/4/2019 | She et of
File : D:\C UFE\P roje ct\Final P C B\She et4. S chDocD | r a wn By:


Numbe r | R evision

: 12/4/2019 | She et of
File : D:\C UFE\P roje ct\Final P C B\She et5. S chDocD | r a wn By:
